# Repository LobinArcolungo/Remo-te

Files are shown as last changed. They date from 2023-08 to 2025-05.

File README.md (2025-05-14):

# Remo-te

## Remo-te?
YES! This project aims to build an automated machine for tea brewing!<br>
Imagine jumping into your car after work and having to drive for quite some time. Wouldn't be great if once you get home a hot cup of freshly brewed tea is waiting for you just at the perfect temperature for you to not burn your tongue? And what if this was just a tap away from your finger?
<br>
<br>
Now that's what we are talking about! and you ca find beelow all the documentation that i wrote during the process of making this machine. Take it not as a tutorial but more as an inspiration for your very own version.<br>
<br>

## Materials
### for the electronic part we will need
- Arduino nano for hardware driving.
- ESP 8266 or Arduino nano IoT for cloud connection.
- 2 Relays 5Vdc 10A.
- 2 Micro Servo 9g MS18.
- L298N driver for stepper motor.
- Power supply 12v 3A.
- Power supply 5V 1A for autonomus powering the boards, the relais and the servo motors.
- A generic 12V pump and a small pipe.
- A stepper motor, i used 17OM-J349-G2VS Minabea Motor.
- A Breadboard to hold all the components.
- A triple plug to join al the power cables into one plug to be attached to the house power grid.

### for the mechanical part we will need
- To print all the .stl files in the "prints" folder
- A water tank to hold the water
- An electrical boiler with auto-shut-off function when boiling point is reached
- A plastic pulley
- A box to hold the circuitry
- About 3 meters of thin fishing line: a piece is used to connect the servo motor which will turn on the boiler and another piece has to be divided in three pieces and braided to make it stronger which will hold the boiler during the pouring process.
- (optional) A bearing to make the twine flow easily
- Of course a teapot to pour te water in!

## Circuit
In the folder "circuit" can be seen the history of the circuits. The last version is this one
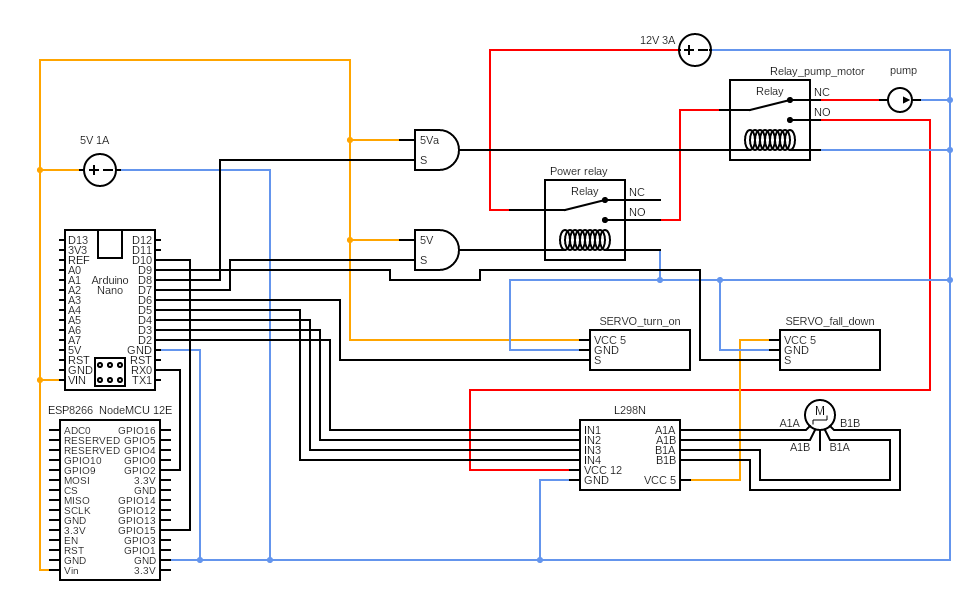
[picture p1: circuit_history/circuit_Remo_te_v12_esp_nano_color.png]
Alt Image of the circuit


The boards are powered autonomously with the 5V 1A power supply.
The pins involved for the Arduino nano are:
- 2,3,4,5 respectively for the first coil (2,3) and the second coil (4,5) of the stepper motor
- 6 controls the servo motor which turns the boiler power on
- 7 controls the power supply relay
- 8 controls the "power router" relay which choses between pump and stepper motor 
- 9 controls the servo motor which starts the falling process
- 10 sends to the ESP board a signal "TE_READY" when the preparation is ended
- RX for serial UART receiver

The pins involved for the ESP are:
- D4 (or GPIO 2) for UART transmission
- D8 (or GPIO 15) for TE_READY signal

this is a photo of my setup.
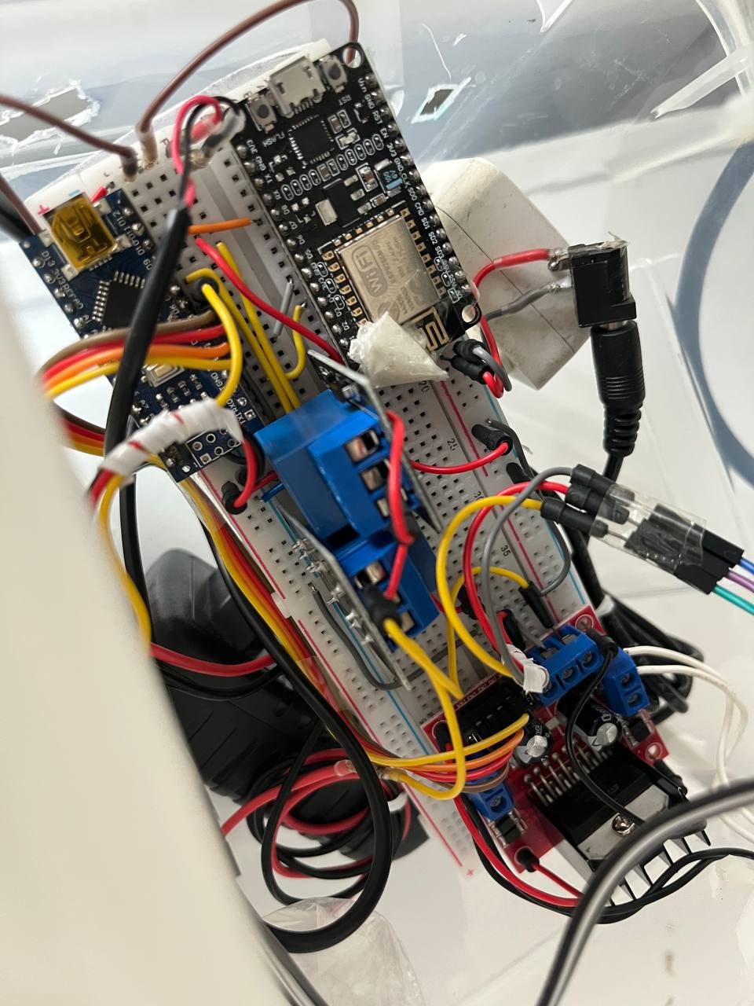
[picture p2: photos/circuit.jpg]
Alt Photo of the circuit


and a circuit made with fritzing
![Alt Image made with fritzing]()

## Code
The most updated code is the folder, one with 
It provides a series of functions callable from serial communication and allows to test all the functionalities one by one. The code is commented and i think it is pretty easy to understand

## Mechanical building
The assembling process is simple and easily customizable depending on your setting. the only few important rules are 
- the water tank should lay below the boiler otherwise the pump will let the water flow into the boiler
- the circuit board should rest in a place relatively safe from water drops
- the motor should stay in the specific housing in the printed part "remo_te dock.stl"
- the pulley should be attached to the motor and should roll and unroll the fishing line to make the boiler pour the hot water

## Video
Here can be found the demostrating video of the functioning

Video showing remote tea making functionality

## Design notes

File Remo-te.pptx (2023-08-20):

## Remo-te

Making... some tea

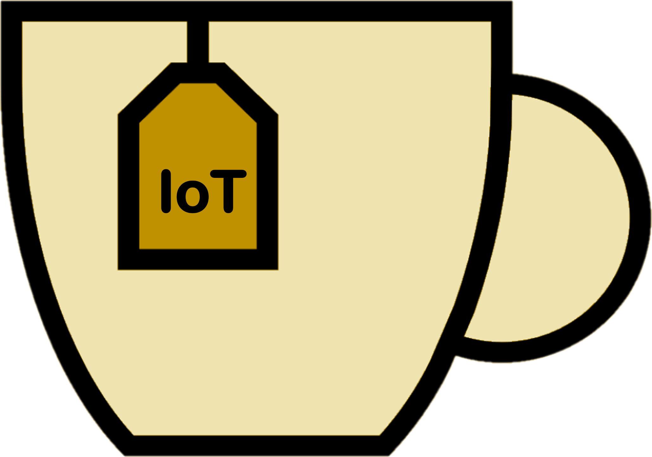
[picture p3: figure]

Giacomo Cerino - Agosto 2023

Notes: Buongiorno a tutti oggi vi parlerò del mio progetto, remo-te, dove te sta per tè, quello che si beve.

## Remo-te

Making... some tea

L’idea

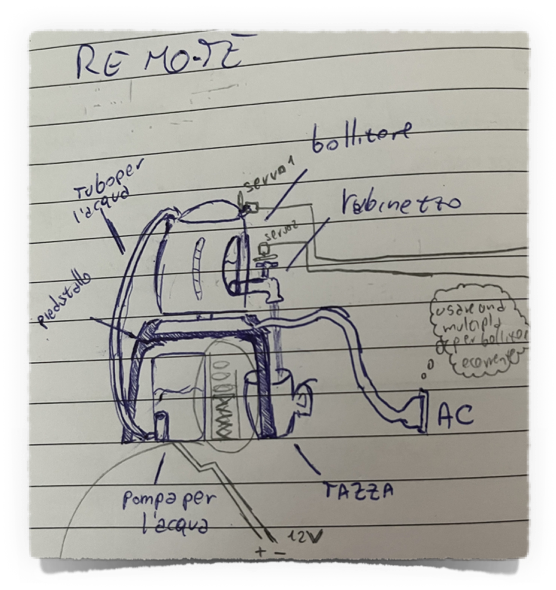
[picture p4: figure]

Giacomo Cerino - Agosto 2023

Remo-te

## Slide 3

L’idea

Preparare il tè
Automaticamente
Con un tap su un’applicazione

Remo-te

Giacomo Cerino - Agosto 2023

I problemi

Motore

Caduta

Comunicazione

Voltaggio

Stampa 3D

Attrito

Elettrovalvola

Bustina di te

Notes: L’idea è quella di avere un dispositivo capace di preparare il te in maniera automatica e non supervisionata.
Attraverso un controllo remoto semplice si può così preparare una tazza di te con largo anticipo e averlo perciò a temperatura ambiente, pronto per essere raffreddato con un po’ di ghiaccio oppure fare in modo che all’arrivo il te sia ben caldo per le giornate invernali. Qui possiamo vedere il bozzetto iniziale in cui era previsto l’utilizzo di una pompa per riempire il bollitore, un rubinetto per versare l’acqua calda nella tazza, e un abbozzato sistema di caricamento delle bustine di tè. Per accendere il bollitore e controllare il flusso d’acqua avrei usato dei servomotori e il tutto sarebbe stato montato su un piedistallo stampato in 3D. Tutto semplice no?

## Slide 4

L’idea

Giacomo Cerino - Agosto 2023

I problemi

Motore

Caduta

Comunicazione

Voltaggio

Stampa 3D

Attrito

Elettrovalvola

Bustina di te

Remo-te

Giacomo Cerino - Agosto 2023

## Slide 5

Motore

Stampa 3D

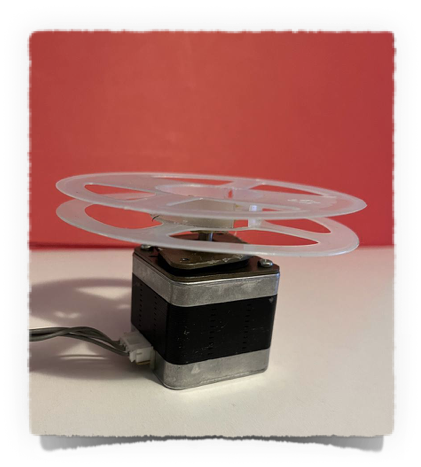
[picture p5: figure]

Elettrovalvola

I problemi

Attrito

Bustina di te

Caduta

Comunicazione

Giacomo Cerino - Agosto 2023

Voltaggio

Remo-te

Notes: Ecco…
Questi sono i problemi che mi sono trovato ad affrontare non li affronterò tutti nel dettaglio perciò spenderò due parole adesso su ognuno.
Il primo è l’elettrovalvola. Il mio progetto di estrarre l’acqua calda molto semplicemente grazie alla gravità è stato bocciato in quanto giudicato fallimentare dal commesso del negozio di idraulica in cui mi sono recato ().
Perciò il design del progetto è radicalmente cambiato e ha fatto scaturire tutta una serie di altri problemi.
Il motore, e l’attrito su cui arriveremo dopo. Il problema della stampa 3D è un problema di tempistiche, in quanto avevo solo una possibilità di stampare i pezzi voluminosi prima della pausa estiva degli uffici di alma labor.
Il problema della caduta è attualmente risolto in parte in quanto non è garantito che il meccanismo funzioni sempre. Comunque è stato risolto da un servomotore, il problema della bustina di te è considerabile risolto ma con una versione beta in quanto c’è un problema di sgocciolamento e ampio margine di miglioramento del meccanismo.

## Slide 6

Stampa 3D

Motore

I problemi

Funzionamento dei motori passo passo
Driver dedicato
Scrittura del software
Gestione surriscaldamento

Attrito

Elettrovalvola

Bustina di te

Caduta

Remo-te

Giacomo Cerino - Agosto 2023

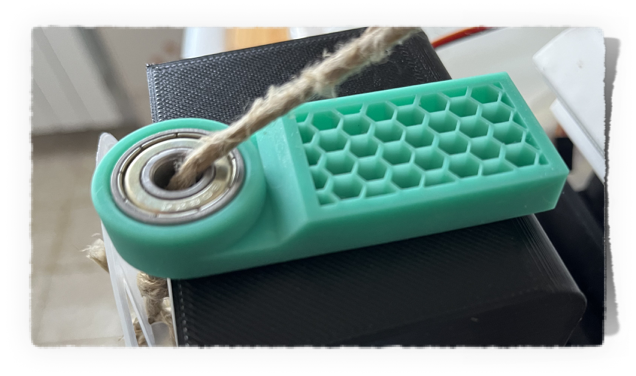
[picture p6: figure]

Attrito

Voltaggio

Comunicazione

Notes: Il motore passo passo che avevo a disposizione non poteva essere controllato da arduino da solo e neanche da un normale chip per motori, cioè un ponte H. serviva un chip dedicato di cui fortunatametne disponevo e con cui mi sono dovuto interfacciare e capire le meccaniche. Non ho usato librerie già pronte ma piuttosto ho seguito una guida di un canale youtube (ScienceFun) il cui codice permette anche di determinare la potenza con cui muovere il motore… ciò più avanti avrebbe generato un problema… infatti fino alla risoluzione del problema della caduta, ho lavorato sempre su una scheda arduino nano, in vista poi di traslare il codice su un ESP 8266

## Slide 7

Motore

Attrito

Voltaggio

I problemi

Strofinamento
Disegno 3D
Minimizzazione del volume

Remo-te

Giacomo Cerino - Agosto 2023

Vs

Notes: L’attrito è stato un problema diciamo, non fondamentale da risolvere a prima vista, ma in realtà l’attrito oltre a rovinare il tirante ch eè, si, facilmente sostituibile (perché fino a quel punto era fatto di spago) richiede anche molta più energia da parte del motore in quanto parte della potenza viene dissipata durante lo strofinamento.

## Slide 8

Attrito

Voltaggio

I problemi

Transistor e Relays
Componenti incompatibili
Usare meno schede possibili

Comunicazione

UART

Vs

Remo-te

Giacomo Cerino - Agosto 2023

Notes: Come dicevo prima

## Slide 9

Le tecnologie:

Voltaggio

I problemi

Differenza del numero di porte seriali
Impossibilità di debug e funzionamento simultaneo
Compromesso

Comunicazione

UART

Vs

Remo-te

Giacomo Cerino - Agosto 2023

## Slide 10

Voltaggio

I problemi

Differenza del numero di porte seriali
Impossibilità di debug e funzionamento simultaneo
Compromesso

Comunicazione

Le tecnologie:

UART

Vs

Remo-te

Giacomo Cerino - Agosto 2023

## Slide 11

Voltaggio

I problemi

Differenza del numero di porte seriali
Impossibilità di debug e funzionamento simultaneo
Compromesso

Comunicazione

Le tecnologie:

Comunicazione bidirezionale asincrona

UART

Vs

Remo-te

Giacomo Cerino - Agosto 2023

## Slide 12

Le tecnologie:

51%

UART

Segnale digitale di notifica +
Comunicazione monodirezionale asincrona

Remo-te

Remo-te

Giacomo Cerino - Agosto 2023

Arduino e ESP8266

Transistor e Relays

Stepper
Motor

Design e stampa 3D

Servo motori

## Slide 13

Il circuito

51%

Le tecnologie:

Arduino e ESP8266

UART

Transistor e Relays

Stepper
Motor

Design e stampa 3D

Giacomo Cerino - Agosto 2023

Servo motori

Remo-te

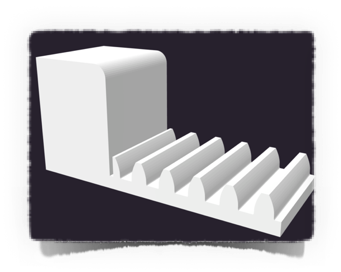
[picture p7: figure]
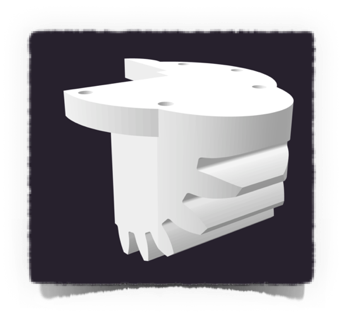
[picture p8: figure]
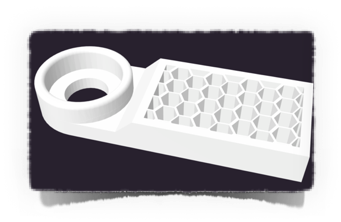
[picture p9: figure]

Segnale digitale di notifica +
Comunicazione monodirezionale asincrona

Remo-te

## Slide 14

Transistor e Relays

UART

Le tecnologie:

Arduino e ESP8266

Design e stampa 3D

Stepper
Motor

Servo motori

Remo-te

Giacomo Cerino - Agosto 2023

Segnale digitale di notifica +
Comunicazione monodirezionale asincrona

Remo-te

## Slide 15

Il circuito

51%

Le tecnologie:

Arduino e ESP8266

UART

Transistor e Relays

Stepper
Motor

Design e stampa 3D

Giacomo Cerino - Agosto 2023

Servo motori

Remo-te

Segnale digitale di notifica +
Comunicazione monodirezionale asincrona

Remo-te

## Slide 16

IoT Cloud

Variables
Devices
Dashboard
Things
Web Editor

Le tecnologie:

Il circuito

Remo-te

Giacomo Cerino - Agosto 2023

Arduino e ESP8266

IoT Remote

UART

Microcontroller

Transistor e Relays

Stepper
Motor

Design e stampa 3D

Servo motori

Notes: Due power supply,
i relays sono un po’ modificati,
il bollitore non è nel circuito

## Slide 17

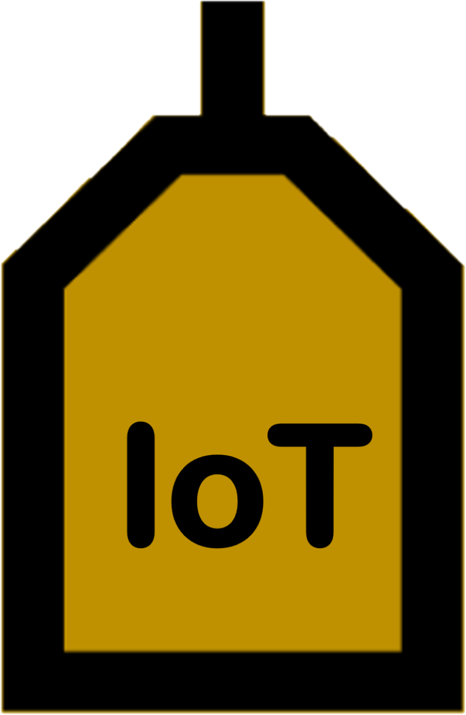
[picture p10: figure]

Il Remo tè

IoT Cloud

Variables
Devices
Dashboard
Things
Web Editor

Il cloud

Microcontroller

IoT Remote

Remo-te

Giacomo Cerino - Agosto 2023

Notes: Cos’è IoT Cloud
IoT Remote
Codice
Come mi interfaccio al cloud

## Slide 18

Il Remo tè

IoT Cloud

Variables
Devices
Dashboard
Things
Web Editor

Il cloud

Microcontroller

IoT Remote

Remo-te

Giacomo Cerino - Agosto 2023

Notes: Cos’è IoT Cloud
IoT Remote
Codice
Come mi interfaccio al cloud

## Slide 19

Il cloud

Il Remo tè

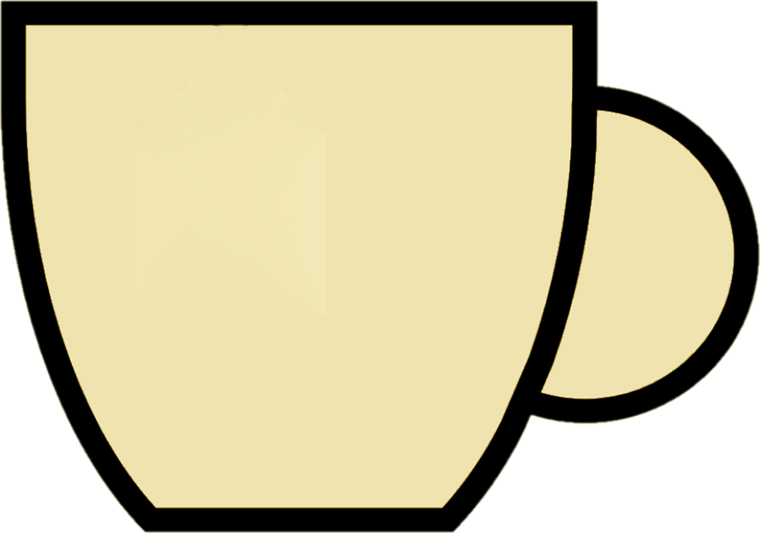
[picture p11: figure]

Dovrebbe essere pronto

Giacomo Cerino - Agosto 2023

Remo-te

IoT Cloud

Variables
Devices
Dashboard
Things
Web Editor

Microcontroller

IoT Remote

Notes: Di nuovo bustina di te

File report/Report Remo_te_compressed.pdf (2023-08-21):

# Remo-te

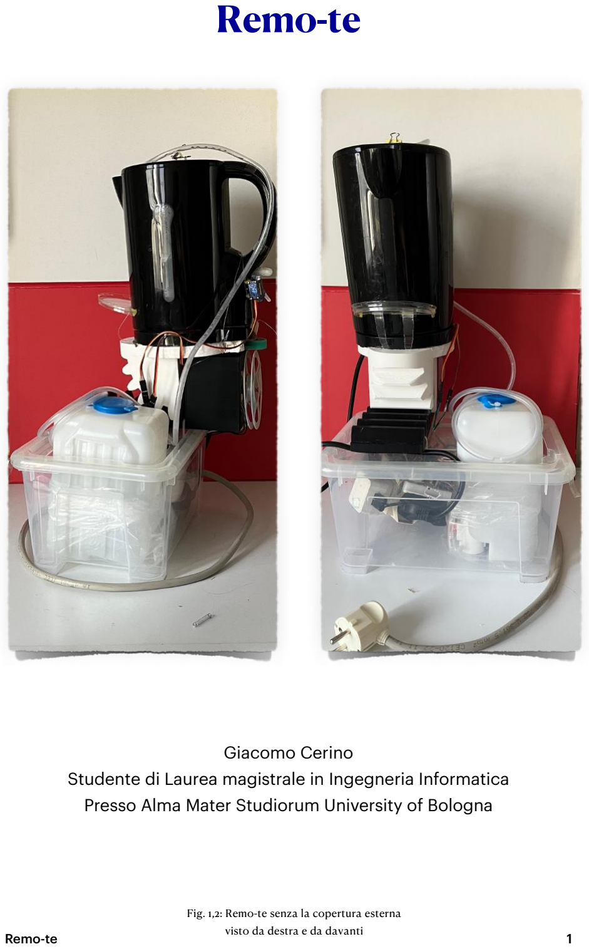
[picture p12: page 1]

Giacomo Cerino
Studente di Laurea magistrale in Ingegneria Informatica Presso Alma Mater Studiorum University of Bologna
Remo-te | 1

Fig. 1,2: Remo-te senza la copertura esterna visto da destra e da davanti

## Indice

Indice | 2
Introduzione | 3
Il progetto iniziale | 4
Sviluppo della soluzione | 4
Problema dell’elettrovalvola | 5
Problema della stampa 3D | 5
Problema del motore | 6
Problema dell’attrito | 8
Problema della caduta | 10
Problema del voltaggio | 11
Problema della comunicazione tra schede | 12
Problema della bustina di te | 13
Interfacciamanto a ArduinoCloud | 14
Materiali e metodi utilizzati | 14
Modellazione 3D | 14
Stampa 3D | 14
Schede utilizzate | 15
Componenti elettronici | 15
Componenti non elettronici | 16
Disegno del circuito | 16
Programmazione delle schede e debug | 16
Interfacciamento al Cloud | 17
Risultati ottenuti | 17
Sviluppi futuri | 17
Telegram bot | 18
Aggiunta parametri come zucchero e tempo di infusione | 18
Aggiunta di sensori | 18
Open Source | 18
Bibliografia e Sitografia | 19
Remo-te | 2

## Introduzione

Il progetto è nato come una sfida per raggiungere un certo livello di comodità nella preparazione del te. A molte persone il te piace caldo e appena preparato, a me per esempio piace freddo. Il problema con il te freddo è che bisogna prima prepararlo per infusione in acqua calda e poi aspettare che si raffreddi.
Per velocizzare questo processo si potrebbe utilizzare un frigorifero o del ghiaccio. Entrambe queste due soluzioni generano problemi: mettendo il te nel frigorifero si alza di molto la temperatura del frigorifero in quanto in un ambiente a circa 4°C si introduce un elemento a più di 90 °C. Inoltre viene generata della condensa che per la mia esperienza peggiora il sapore del te rendendolo più amaro. Utilizzando del ghiaccio il tè inevitabilmente si diluisce e inoltre bisogna accertarsi di disporre del ghiaccio nel freezer.
Perciò mi è venuto in mente che sarebbe comodo poter avviare con un certo anticipo rispetto al mio arrivo a casa la preparazione di una certa quantità di te. Il risultato del processo autonomo di infusione mi aspetterà a casa raffreddandosi. Chiaramente questo progetto è adatto anche a preparare il te mentre si è sulla via del ritorno dal lavoro. In modo che arrivati a casa il te sia ancora caldo.
Remo-te | 3

## Il progetto iniziale

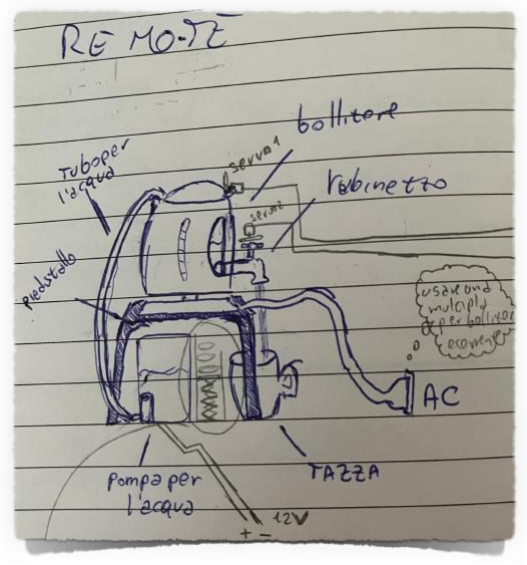
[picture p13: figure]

Il progetto iniziale doveva essere un macchinario abbastanza semplice che utilizzava una pompa per riempire un bollitore, un servomotore per innescare il processo di bollitura e una ulteriore pompa per pompare l’acqua calda nella tazza o nella teiera. Inoltre era previsto u n s i s t e m a d i a r r o t o l a m e n t o e srotolamento della cordicella di una bustina di te in modo da poter controllare anche il tempo di infusione. Alla base del bollitore era prevista l'aggiunta di un “rubinetto controllato e l e t t r o n i c a m e n t e ”, c o m e u n
elettrovalvola o un dispositivo da
giardinaggio.
Il bozzetto del design era abbastanza compatto prevedeva di assomigliare a una macchinetta del caffè dalla cui parte bassa si poteva estrarre la tazza piena di te.

## Sviluppo della soluzione

In questa sezione descrivo la successione dei problemi che si sono presentati durante la realizzazione. In pratica è un riassunto di tutti i passaggi e le iterazioni che hanno portato al primo prototipo funzionante.
Ho cominciato comprando online una pompa provvista di serbatoio per acqua. La scelta è ricaduta su una pompa universale per tergicristalli. Essendo pronta all’uso avrei solo dovuto provvedere all'energia elettrica. Prima di utilizzarla per preparare del te ho trattato il serbatoio con dell'aceto e del bicarbonato per rimuovere il cattivo odore che sprigionava.
Nel frattempo ho comprato un bollitore in un negozio dell’usato e mi sono recato in un negozio di componenti elettronici e idraulici dove ho comprato due
Remo-te | 4

Fig. 3: Bozzetto iniziale relais e ho chiesto informazioni riguardo all'idea dell’elettrovalvola e mi hanno consigliato un posto più specializzato dove recarmi.

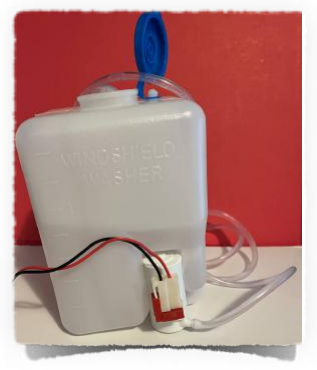
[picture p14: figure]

### Problema dell’elettrovalvola

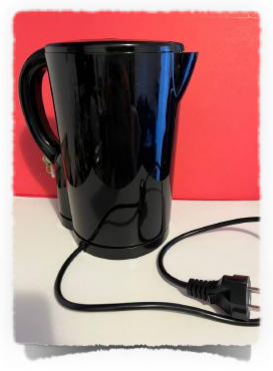
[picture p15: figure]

Una volta recatomi in loco, il commesso mi ha risposto che l'idea originaria di perforare il bollitore per aggiungere l’elettrovalvola oltre che abbastanza costosa sarebbe stata fallimentare in quanto sicuramente la tenuta stagna si sarebbe presto guastata a causa della dilatazione termica dovuta la variazione della temperatura dell'acqua che per definizione si genera dentro un bollitore.
Soluzione: Tornato a casa mi sono messo a pensare a una soluzione alternativa per ottenere comunque il risultato previsto dal progetto. E ho pensato a un sistema di ingranaggi in grado di inclinare il bollitore in modo da versare gradualmente l'acqua dentro un recipiente e poi ripristinare la sua posizione verticale.

### Problema della stampa 3D

Ho disegnato il sistema di ingranaggi in 3D aiutandomi con un CAD e mi sono recato in un laboratorio dell'università per farmeli stampare con stampanti FDM in PLA. Purtroppo viste le imminenti vacanze estive ho potuto fare solamente una stampa e come è facile intuire il mio disegno aveva delle imperfezioni di cui mi sono reso conto solamente una volta ottenuti i pezzi.

Fig. 4: Pompa universale per tergicristalli con tubo e
serbatoio

Fig. 5: Bollitore elettrico da 1.7l di capacità massima

Remo-te | 5

La progettazione e la stampa di pezzi in 3D è anche detta prototipazione veloce. Per avere un prototipo funzionante di solito ci vuole qualche iterazione in modo da perfezionare il design ma in questo caso non è stato possibile.
Soluzione: Seppur imperfetti, i pezzi che avevo ottenuto riuscivano a soddisfare il bisogno primario per cui li avevo stampati, ovvero incastrarsi fra loro e ruotare di 90° l’uno sull’altro. L'imperfezione era l’incastro con la parte inferiore del bollitore, ma lavorando una mattina con un saldatore, un Dremel, e un adattatore fatto in cartone sono riuscito a produrre un incastro che funziona. Ad ogni modo non avrei avuto la possibilità di stampare a filamento altri pezzi così voluminosi fino a settembre.

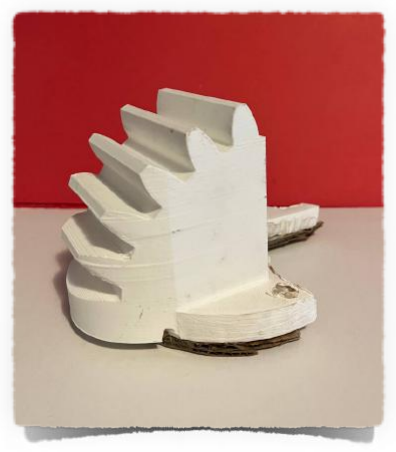
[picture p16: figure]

### Problema del motore

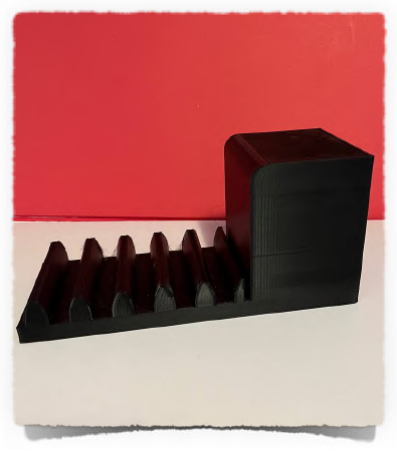
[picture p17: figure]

Per azionare il sistema di ingranaggi in modo automatico sarebbe stato necessario l'utilizzo di un motore a cui avrei attaccato una puleggia per allungare o diminuire la lunghezza di un tirante che mantiene in equilibrio il bollitore. A casa avevo a disposizione un motore passo passo di cui non ricordo la provenienza. La sfida è diventata quella di farlo funzionare in modo soddisfacente.

Remo-te | 6

Fig. 6: Boiler, ovvero il pezzo da attaccare al bollitore

Fig. 7: Dock, ovvero il pezzo su cui si appoggerà il bollitore

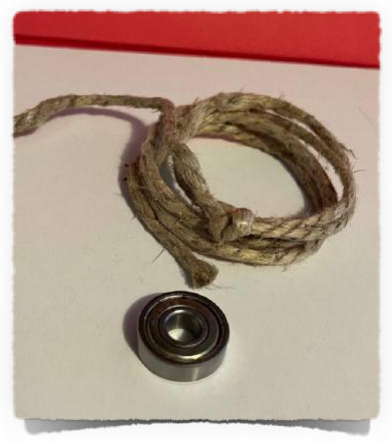
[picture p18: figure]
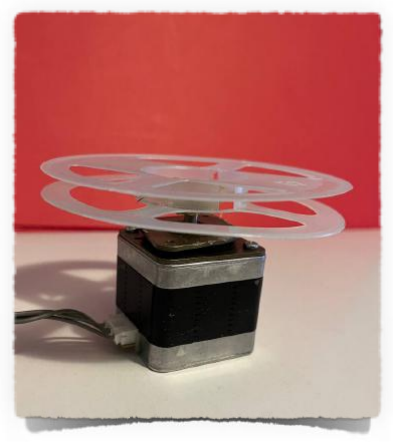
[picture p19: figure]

In quel momento io avevo a disposizione solamente un Arduino UNO e perciò cominciai a sperimentare utilizzando soltanto i segnali dell’Arduino UNO. Dopo poco tempo mi sono reso conto che avrei avuto bisogno di un driver per motori passo passo. Avendo come ostacolo sempre le vacanze
estive ho cercato di trovare una soluzione che non
prevedesse l'acquisto di uno di questi driver.
Operando una ricerca tra i componenti elettronici che avevo a disposizione ho trovato un driver L9110 adatto per la guida di due motori a corrente continua oppure un motore passo passo. Ho cominciato a scrivere il codice utilizzando questo driver ma dopo qualche esperimento mi sono reso conto che il problema era che il mio motore passo passo
richiedeva una quantità di corrente e tensione tale che
non poteva essere gestita da questo chip.

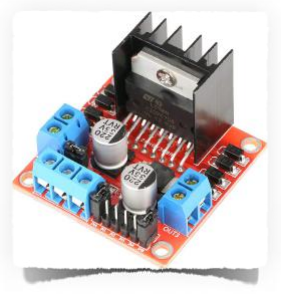
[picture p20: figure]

Soluzione: Mi sono ricordato a questo punto che un mio amico mi aveva portato un driver L298N. Un driver vecchio per due motori a corrente continua o un motore passo passo. Un motore che ha dei noti problemi in quanto si surriscalda fin troppo facilmente spegnendosi ma tutto sommato un motore che poteva gestire

Remo-te | 7

Fig. 9: Cuscinetto a sfera e spago che inizialmente era usato come tirante.

Fig. 8: Motore passo passo “17OM-J349-G2VS Minabea Motor” con puleggia di plastica incollata

Fig. 10: Driver L298N

(fino a un certo punto) la corrente che gli avrei fornito. Mi sono messo perciò a scrivere il codice su Arduino per provare a guidare il motore attraverso il driver e per ottenere una versione funzionante mi è stato molto utile guardare alcuni video su YouTube [2],[3], e in particolare il video di Science Fun [1].
Come ho detto il driver del motore è soggetto a surriscaldamento e spegnimento improvviso, perciò è fondamentale fornire energia al motore soltanto per il tempo strettamente necessario. Per fare ciò ho usato i due relais per creare un sistema di gestione della corrente in grado di spegnersi appena il motore non sia più necessario.

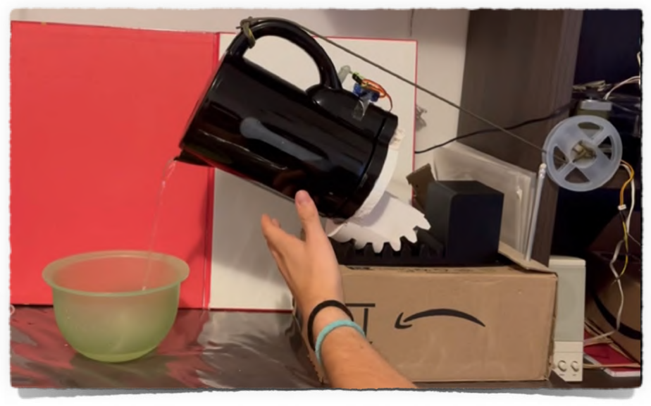
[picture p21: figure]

### Problema dell’attrito

Inizialmente il tirante che avevo pensato di usare era fatto di spago (ancora prima da un laccio di una scarpa). Uno dei difetti del design dei pezzi stampati in 3D era che avevano alcuni spigoli non smussati. Perciò lo spago scorrendo e sfregando

Remo-te | 8

Fig. 11: Fotogramma di uno dei primi video in cui stavo provando per la prima volta il sistema del motore con la puleggia. Si può vedere come i due pezzi stampati in 3D si incastrano tra loro, il bollitore possa essere acceso con un servo motore applicato sul retro, la puleggia srotoli e arrotoli un laccio da scarpe che avevo usato come tirante, l’acqua fuoriesca dal bollitore per finire in un recipiente.

sullo spigolo si sarebbe presto deteriorato, questo mi ha fatto pensare al problema dell’attrito.
L'attrito rovina il tirante e stressa di più il motore richiedendo più dispendio di energia.
Soluzione: Ho disegnato in 3D un alloggio per un cuscinetto a sfera attraverso il quale far passare il tirante basandomi su un design di Hondjog1 (https://www.thingiverse.com/Hondjog1) [4],[5]. Non è il metodo più efficiente per eliminare l'attrito ma il metallo genera molto meno attrito e la componente mobile del cuscinetto agevola eventuali rotazioni del tirante. Ho detto prima che non avrei avuto la possibilità di stampare questo pezzo con una stampante a filamento, e infatti in questa occasione ho usato la mia stampante a resina. Stampare prototipi in resina non è particolarmente indicato perché:
- È sconsigliabile stampare grandi volumi: la resina non può avere spazi vuoti all'interno dei modelli in quanto essendo liquida rimarrebbe all'interno e non verrebbe solidificata con il processo di curing.
- Nel caso in cui si stampino pezzi che devono combaciare al millimetro con altri, è consigliabile utilizzare un orientamento verticale dell'asse di incastro in modo tale da non avere problemi di deformazione durante la stampa.
Remo-te | 9

(Sopra) Fig. 12: Foto dell’alloggio per cuscinetto a sfera, come si può vedere è stampato in resina e ha molti fori esagonali per diminuire molto il volume della resina utilizzata ma mantenere la stabilità e la rigidezza, inoltre i fori sono stati molto utili per incollarlo al pezzo sottostante. (Notare lo spigolo nero).
(Sinistra) Fig. 13: Fotogramma del primo video in cui ho preparato un vero e proprio te. È ripreso dall’alto. La scatola è ancora di cartone e l'alloggio per il cuscinetto a sfera è ancora fatto con materiali di fortuna per evitare l'eccessivo sfregamento

Per questo motivo il disegno che ho fatto occupa poco volume effettivo perché ha numerosi fori esagonali. Inoltre l'alloggio per il cuscinetto a sfera è stato stampato con l'asse di incastro allineata con quella verticale e perciò è stato un successo alla prima stampa.
In aggiunta ho sostituito il tirante di spago con un tirante fatto di lenza da pesca intrecciata in modo da aumentare la resistenza e avere uno stile più elegante.

### Problema della caduta

A questo punto avevo ottenuto un sistema funzionante di gestione dell'inclinazione del bollitore. L’unico guaio era che il bollitore in posizione di equilibrio non era soggetto all'influenza del motore, in pratica doveva essere sbilanciato in modo da poter poi essere inclinato a piacere grazie al motore. Soluzione: grazie a un servo motore collocato sotto la base del bollitore si riesce a sbilanciare quest'ultimo in avanti grazie a una rotazione del braccio di 90°.

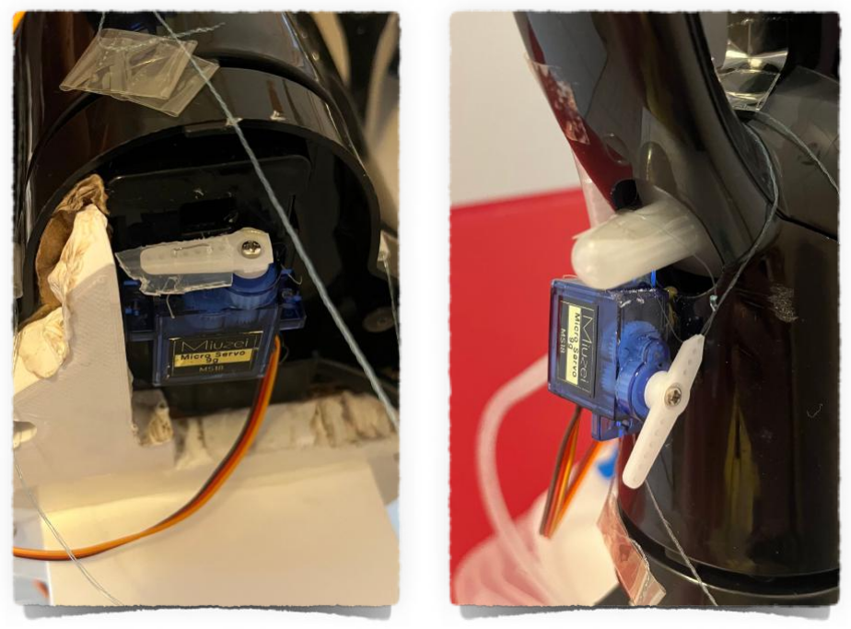
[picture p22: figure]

Remo-te | 10

Fig. 14: Servo motore applicato
alla base del bollitore

Fig. 15: Servo motore che si occupa dell’accensione del bollitore ruotando in senso orario

Ne approfitto visto che stiamo parlando di servomotori per spiegare che il sistema di accensione del bollitore è anch’esso operato da un servo motore che tira una cordicella di lenza da pesca corta in modo da azionare l'interruttore che poi ritornerà alla posizione iniziale quando il bollitore si spegnerà da solo.
Problemi noti: Il servo motore non è particolarmente performante e perciò non riesce a sollevare il peso del bollitore se esso è completamente aderente alla superficie del Dock e contiene più di un litro d’acqua. Per questo il motore viene sempre tenuto leggermente inclinato in modo che il servo motore possa eseguire con successo la sua funzione.

### Problema del voltaggio

Dopo aver ottenuto una versione funzionante del primo prototipo che utilizzava Arduino come micro controllore, mi sono messo a traslare il codice sulla scheda ESP8266 Node MCU 12.1. La quale essendo provvista di un modulo Wi-Fi ha la capacità di connettersi a Arduino cloud.
Sebbene inizialmente mi era sembrato un compito facile in quanto le due schede condividono il supporto per il linguaggio di programmazione di Arduino, mi sono presto accorto che il voltaggio operativo delle due schede era differente. Mmentre Arduino opera a 5V ed è quindi in grado di fornire segnali digitali e analogici fino a 5V, la scheda ESP8266 invece opera a 3.3V ed è perciò in grado di inviare segnali digitali e analogici soltanto fino a 3.3V. Per i segnali digitali non sussiste nessun problema in quanto 3.3V è interpretato come logic high anche da componenti che lavorano 5V. Invece per i segnali annalogici la questione è differente: il codice scritto per guidare il motore passo passo utilizza segnali analogici nel range [0,5V]. Dove a 5V si raggiunge la coppia massima per il motore. Questo è importante perché durante il processo di raddrizzamento del bollitore serve più energia di quanta ne serva per farlo inclinare.
Dopo vari esperimenti ho constatato che 3.3V non erano abbastanza per comunicare al motore la potenza necessaria per il raddrizzamento. O almeno non con il Driver L298N.
Insieme alla scheda ESP8266 avevo ordinato anche la sua maschera (ESP8266 motor shield) capace di aumentare i pin disponibili e provvedere, grazie a un'alimentazione esterna, alla gestione di un motore passo passo. Nonostante io ci abbia speso un
Remo-te | 11

paio di giorni sopra, ho trovato poca documentazione a riguardo e quella che ho trovato non mi ha permesso di ottenere un funzionamento del motore accettabile. Soluzione: Dopo aver passato giorni a cercare di tradurre i segnali analogici [6] nel range [0,3.3V] al range [0,5V] ho deciso che la soluzione più pratica sarebbe stata quella di utilizzare due schede. ESP8266 per interfacciarsi al cloud e Arduino nano per controllare tutti i componenti hardware che funzionano a 5V.

### Problema della comunicazione tra schede

Una volta deciso che avrei usato due schede si è posto il problema di come sarebbe avvenuta la comunicazione tra le due.
Ho pensato di usare dei segnali digitali basilari per inviare comandi molto semplici ma avendo studiato durante il corso i protocolli di bus e in particolare il protocollo UART ho deciso di provare con quello. Ho presto scoperto però che mentre ESP8266 ha due porte seriali UART, Arduino nano ne ha solo una.
Ho fatto svariate prove per trovare una soluzione che ponesse il sistema in grado di comunicare in entrambe le direzioni con il protocollo UART.

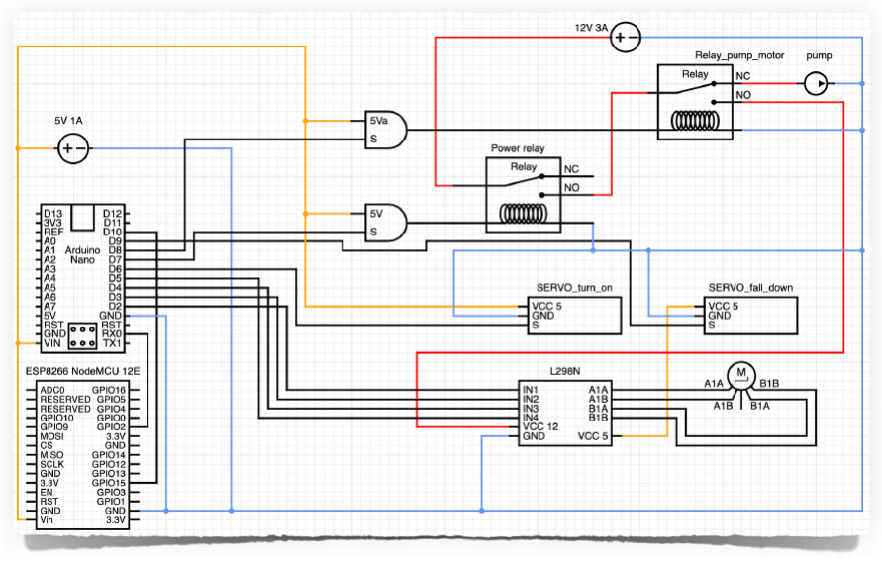
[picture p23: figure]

Remo-te | 12

Fig. 16: Circuito che illustra come le schede sono collegate ai componenti e fra loro

Soluzione: Dopo questi esperimenti ho capito che la cosa migliore data la mia necessità era quella di utilizzare la comunicazione UART soltanto nella direzione da ESP a Arduino nano. E visto che Arduino nano aveva tra i suoi compiti di comunicazione soltanto quello di notificare il momento in cui il te sarebbe stato pronto, nella direzione da Arduino nano a ESP ho utilizzato soltanto un segnale digitale.

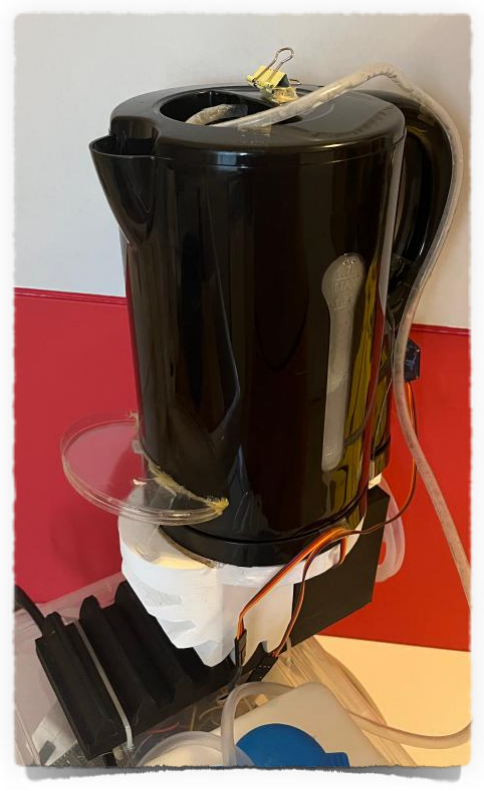
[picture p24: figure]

### Problema della bustina di te

Per come era stato formulato inizialmente il progetto sarebbe stato necessario fornire la possibilità di alzare e abbassare la bustina di te in modo da garantire un determinato tempo di infusione. Tuttavia avendo riscontrato problemi con l'elettrovalvola inizialmente, ho dovuto concentrarmi sulla soluzione di quel problema. Una volta risolto quel problema ho pensato che avrei potuto "riciclare" il movimento del bollitore per muovere anche la bustina di te
Soluzione (anche se classificabile come una beta): Creare la possibilità di fissare al bollitore una bustina di te grazie a un magnete. E aspettare il tempo di infusione prima di risollevare il bollitore in posizione verticale. Inoltre ho aggiunto un piccolo piatto per raccogliere le gocce di te che cadranno dalla bustina.
Remo-te | 13

Fig. 17: Una delle ultime iterazioni, si può notare un piattino di plastica che serve a raccogliere le gocce e una molletta nella parte superiore a contatto con un magnete per fissare la bustina di te

### Interfacciamanto a ArduinoCloud

Durante la risoluzione dei problemi di cui sopra, ho anche portato avanti degli esperimenti per far funzionare l’interfacciamento e la connessione con Arduino Cloud. Ciò che ho constatato è che l’ESP8266 non è sempre collaborativo in quanto a volte rifiuta di connettersi alla rete, e a volte anche se si connette alla rete non si connette con il cloud senza fornire informazioni riguardo agli errori riscontrati. Nella mia esperienza la frequenza di questi avvenimenti è randomica e imprevedibile. La soluzione più comoda sarebbe quella di usare un Arduino nano 33 IoT, provvisto della funzionalità wi-fi e perfettamente integrato con Arduino Cloud.

## Materiali e metodi utilizzati

### Modellazione 3D

La modellazione 3D di questo progetto è stata fatta interamente con Autodesk Fusion 360 in quanto è un software che negli anni ho imparato autonomamente a utilizzare perciò mi sono trovato in un ambiente familiare, in cui sapevo come muovermi.

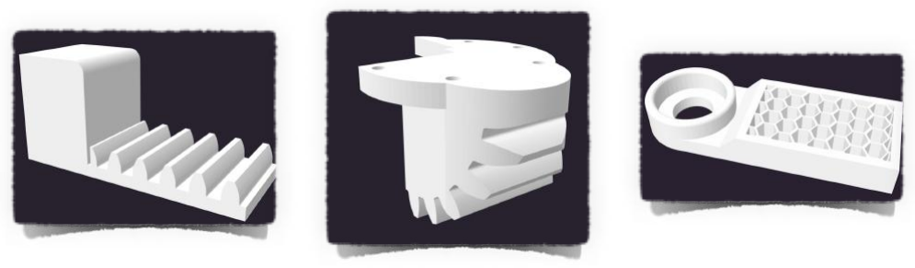
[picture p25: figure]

### Stampa 3D

I primi due pezzi che ho stampato (Dock e Boiler) sono stati stampati con una stampante a filamento in materiale PLA, senza avere particolari caratteristiche di durezza, morbidezza o elasticità. Il terzo pezzo ovvero l'alloggio per cuscinetto a sfera (Bearing_housing) invece è stato stampato con una stampante a resina Elegoo

Remo-te | 14

Fig. 17,18,19: Imagini dei file .stl dei tre pezzi stampati

Saturn in resina lavabile in acqua di colore verde chiaro e applicato successivamente al pezzo chiamato Dock con della colla a caldo.

### Schede utilizzate

Per questo progetto sono effettivamente necessarie solamente due schede:
- ESP8266 node MCU 12.1 (o scheda analoga capace di connettersi a Arduino Cloud).
- Arduino nano (o scheda analoga capace di fornire segnali a 5V).
Tuttavia per fare vari esperimenti anche con i servomotori io mi sono servito di un ulteriore Arduino UNO che potevo maneggiare con più facilità in quanto non era già inserito nel circuito del dispositivo completo.

### Componenti elettronici

- 2 Relays 5V dc 10A.
- 2 Micro Servo 9g MS18.
- L298N driver per motore passo passo.
- Power supply 12v 3A.
- Power supply 5V 1A per fornire energia alle schede .
- Una generica pompa a 12V e un piccolo tubo.
- Un motore passo passo, io ho usato un “17OM-J349-G2VS Minabea Motor”.
- Una Breadboard per sorreggere tutti i componenti.
- Una presa multipla per unire tutti i dispositivi connessi alla corrente.

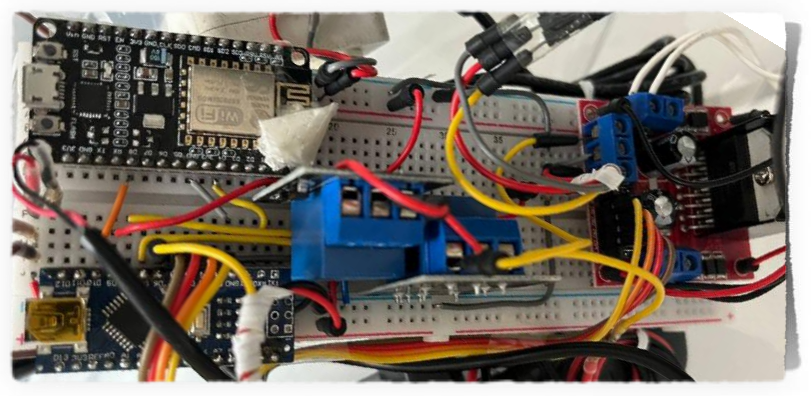
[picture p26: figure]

Remo-te | 15

Fig. 20: Immagine del circuito visto dall’alto

### Componenti non elettronici

- Un cuscinetto a sfera.
- Una scatola per contenere il tutto.
- Della lenza da pesca.
- Una piccola puleggia.
- Nastro adesivo.
- Un piccolo raccoglitore per l’acqua che sgocciola dalla bustina di te.
- Una molletta.
- Un magnete.
- Fascette da elettricista per fissare il Dock alla scatola.

### Disegno del circuito

Per disegnare il circuito mi sono servito di un sito facile e intuitivo da usare che si chiama circuit diagram [7]. Qui ho trovato la maggior parte dei componenti già pronti, anche se alcuni come la scheda ESP li ho dovuti creare personalmente. Tutto sommato non è stato difficile, però dispendioso in termini di tempo.

### Programmazione delle schede e debug

Per la programmazione dei microcontrollori ho utilizzato in minima parte Arduino IDE per poi passare a Visual Studio Code integrato con l'estensione per Arduino. Visual studio code ha moltissime scorciatoie da tastiera per modificare il testo in maniera veloce ed efficace. Inoltre con l'estensione di Arduino mi ha permesso di monitorare più porte seriali simultaneamente e quindi poter riscontrare in parallelo quello che succedeva in una scheda e nell'altra. Inutile dire che ha velocizzato estremamente lo sviluppo del codice.
Per l'upload del codice su ESP8266, arrivato il momento di programmare l'interfacciamento con il cloud, ho dovuto usare la versione online dell'Arduino IDE, il quale è appositamente pensato per comunicare alla scheda in fase di upload tutte le informazioni necessarie per connettersi al cloud nonché gestire le dipendenze dalle librerie del Cloud. Previa installazione di un agent apposito per interfacciarsi alle schede.
Remo-te | 16

### Interfacciamento al Cloud

Interfacciarsi al cloud, sebbene sembrasse estremamente facile visti i tutorial, è stato brigoso poiché era la prima volta che utilizzavo una tecnologia simile.
Dopo averci speso qualche giorno tra tutorial, testing e debug, sono riuscito a
- rendere visibile la scheda al cloud
- fare l'upload codice
- orchestrare tutte le funzioni e le variabili in modo che funzionassero correttamente tra loro.

## Risultati ottenuti

I risultati ottenuti sono soddisfacenti da un punto di vista funzionale, in quanto il dispositivo riesce con successo a preparare dalle due alle quattro tazze di te, purtroppo il funzionamento non è garantito al 100% in quanto ci sono ancora alcuni aspetti da perfezionare come il sistema di caduta che non è affidabile al 100%. Ciònonostante i video del funzionamento sono reperibili al link [9] insieme alle foto dei componenti utilizzati.
La replicabilità è legata a molte variabili, ma le principali sono il tipo di bollitore e il tipo di motore. Per il resto non è un processo a cui ci si può attenere passo passo, è più una guida su come io ho risolto i vari problemi che mi si sono presentati davanti.

## Sviluppi futuri

Il dispositivo attualmente dispone delle funzionalità essenziali ma sicuramente c'è un ampio margine di miglioramento delle prestazioni.
A partire da un sistema di caduta più affidabile, in quanto quello attuale non riesce a garantire funzionamento ogni volta, sebbene la problematica non si presenti così di frequente. Tra gli altri sviluppi futuri posso pensare a:
Remo-te | 17

### Telegram bot

Sebbene l'applicazione IoT Remote di Arduino sia già abbastanza comoda, si può pensare all'implementazione di un BOT di Telegram che si occupa autonomamente di gestire la comunicazione con il cloud.

### Aggiunta parametri come zucchero e tempo di infusione

Si può aggiungere con facilità un parametro che gestisca il tempo di infusione, in quanto è una variabile che modifica la durata di una determinata porzione della preparazione. Cosa che avviene già a seguito della scelta del numero di tazze, perciò basterebbe replicare quel codice.
Per lo zucchero invece occorre progettare e mettere in funzione una appendice del dispositivo in grado di gestire la quantità di zucchero erogata.

### Aggiunta di sensori

Fotoresistore
Sebbene sia una problematica che si presenta molto poco di frequente, a volte accade che il dispositivo di accensione del bollitore fallisca ad accenderlo. Perciò si può pensare all'aggiunta di un sensore come un foto resistore capace di verificare che la luce del bollitore rimanga accesa e che quindi possa essere in grado di comunicare al dispositivo di effettuare un nuovo tentativo di accensione. Temperatura e ventola
Un'altra problematica che in teoria è gestita ma in pratica non è garantito che lo sia, è il surriscaldamento del driver del motore. Esso nonostante abbia un dissipatore integrato non è garantito che riesca a mantenere la temperatura del chip sotto la soglia limite. Si potrebbe perciò aggiungere un sensore di temperatura e una piccola ventola che possa essere accesa nel caso in cui la temperatura del chip raggiunga una determinata soglia.

## Open Source

Il progetto è libero e documentato interamente con tanto di aggiornamenti giornalieri su GitHub al link [8]

Remo-te | 18

## Bibliografia e Sitografia

Riguardo ai Motori passo passo
[1] https://youtu.be/aKxi7B4-d2U Science Fun
[2] https://www.youtube.com/watch?v=aKxi7B4-d2U
[3] https://www.youtube.com/watch?v=O2LWTBfQ26s Riguardo all’alloggio 3D per il cuscinetto a sfera
[4] https://www.thingiverse.com/hondjog1/designs
[5] https://www.thingiverse.com/thing:4111647
Riguardo ai Transistor per gestire voltaggi differenti
[6] https://electronics.stackexchange.com/questions/296330/how-to-drive-a-relay-from-esp8266-gpio (https://electronics.stackexchange.com/questions/296330/how-to-drive-a-relay-from-esp8266-gpio)
Riguardo al Design del circuito
[7] https://www.circuit-diagram.org/editor/
Riguardo alla documentazione GitHub
[8] https://github.com/LobinArcolungo/Remo-te
[9] https://github.com/LobinArcolungo/Remo-te/tree/main/photos
Remo-te | 19

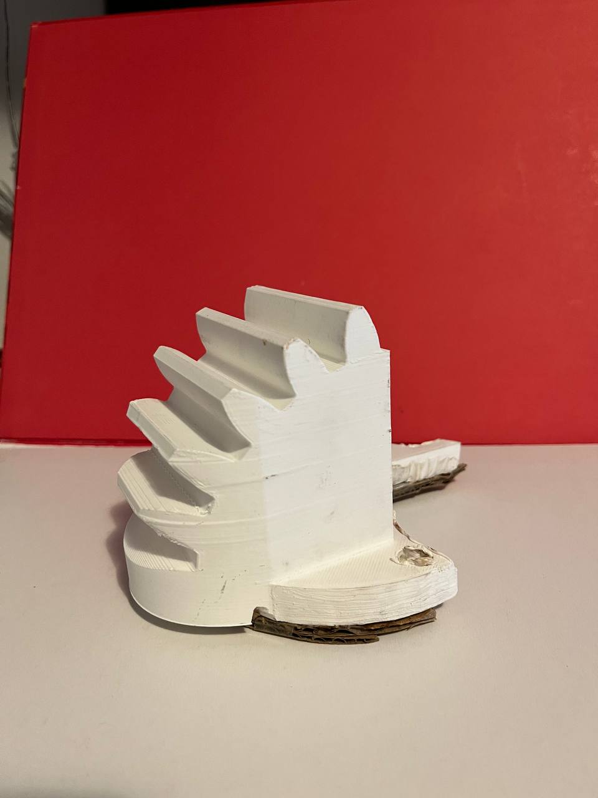
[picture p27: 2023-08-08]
photos/gear.jpg

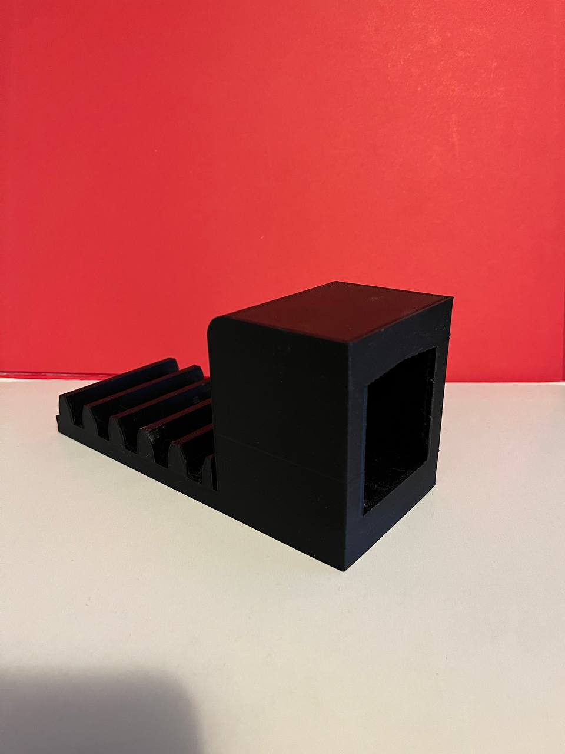
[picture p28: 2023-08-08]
photos/dock_angle.jpg

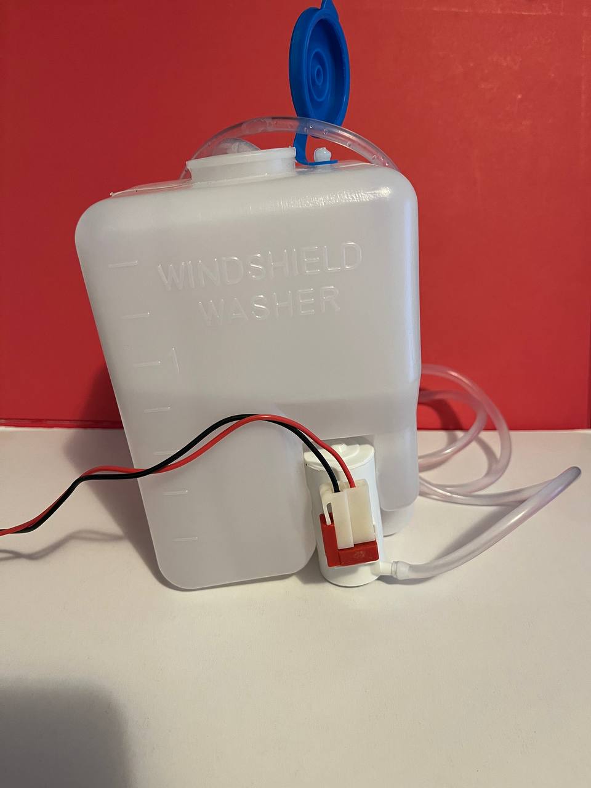
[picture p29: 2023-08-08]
photos/pump_with_tank.jpg

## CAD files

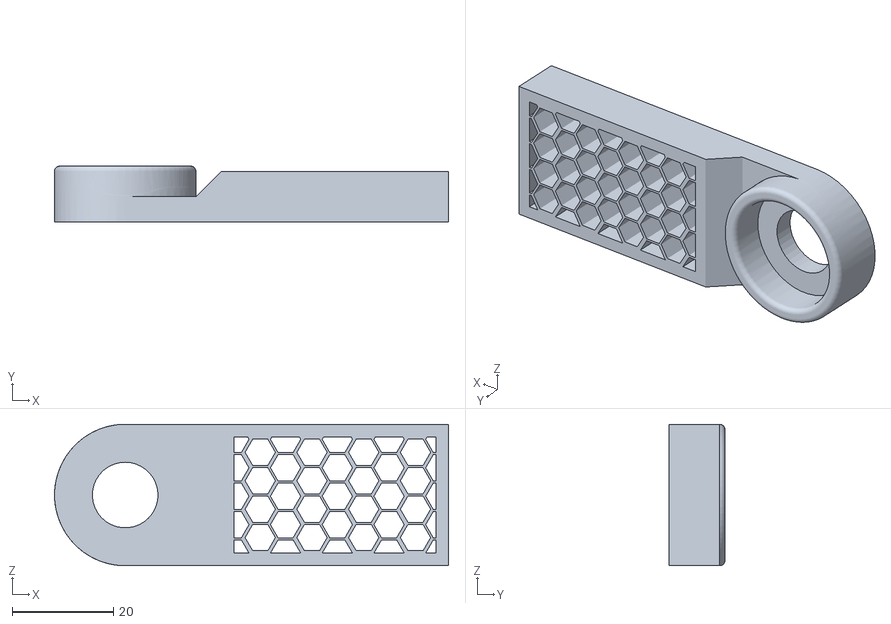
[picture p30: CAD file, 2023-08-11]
prints/bearing_housing.stl
78.0 x 11.1 x 28.0

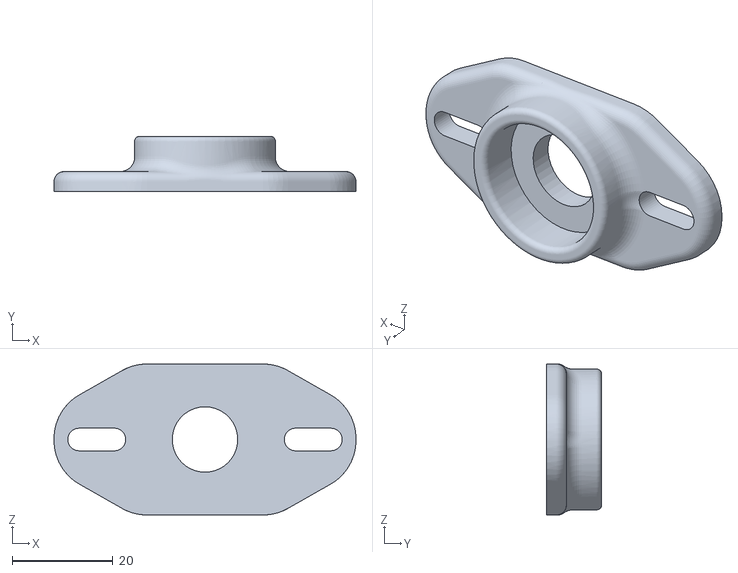
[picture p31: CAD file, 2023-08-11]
prints/lagerhuis_kogellager.STL
60.0 x 11.0 x 30.0

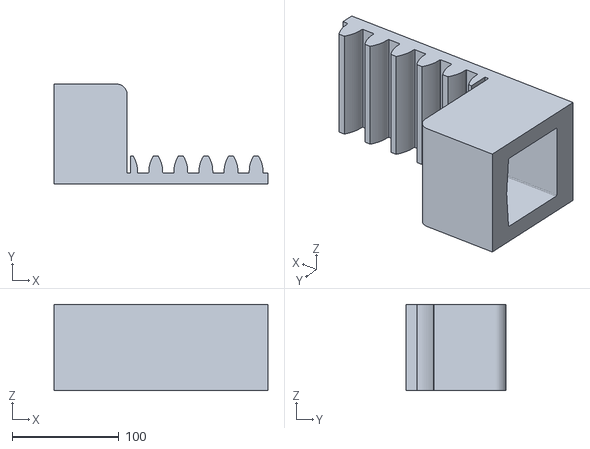
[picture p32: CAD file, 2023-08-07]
prints/remo_te_dock.stl
200.5 x 93.6 x 80.6

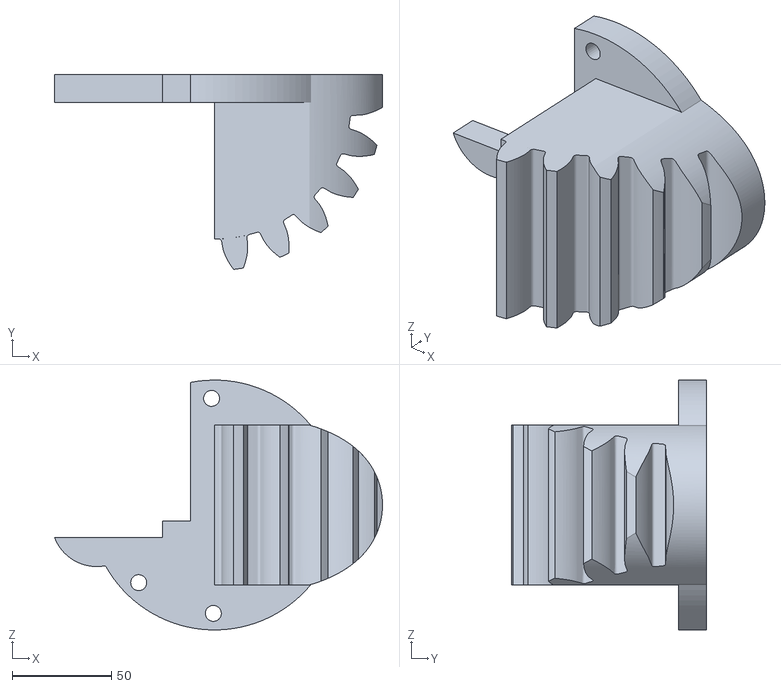
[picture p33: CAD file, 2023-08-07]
prints/remo_te_boiler.stl
165.4 x 98.2 x 126.0

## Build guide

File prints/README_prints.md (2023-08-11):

# Description of the files:

'remo_te_boiler.stl' and 'remo_te_dock.stl' are the main pieces which do most of the job of pouring without making the boiler spilling the water.

'bearing_housing.stl' is the piece who holds the bearing and helps the flowing of the rope decreasind the friction. I designed it starting from the file 'lagerhuis_kogellager.STL' from Hondjog1 downloaded from thingiverse at link: https://www.thingiverse.com/thing:4111647

Feel free to download and modify any of these pieces, expecially because you must modify the remo_te_boiler.stl accordingly to your specific type of boiler

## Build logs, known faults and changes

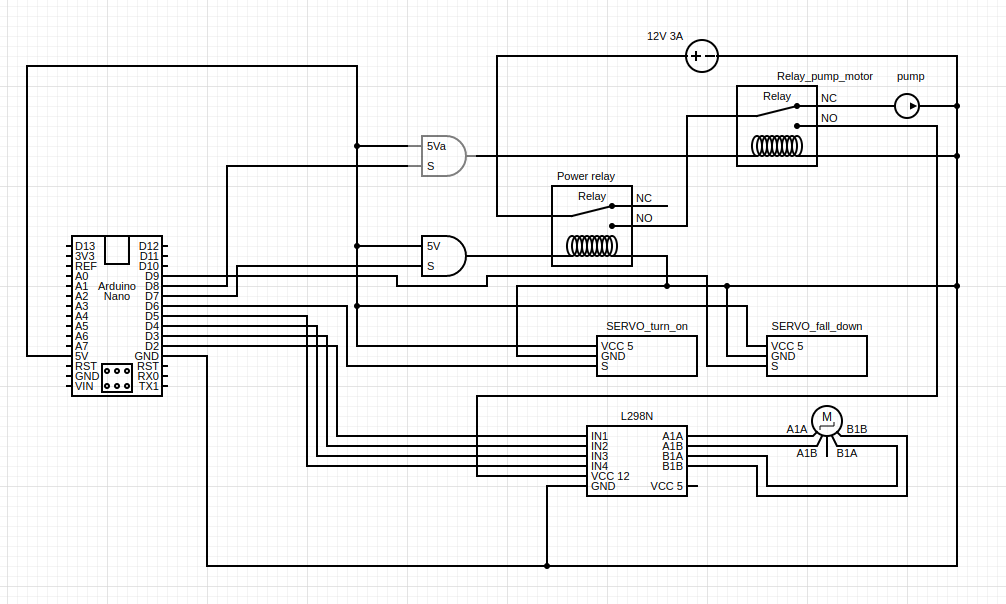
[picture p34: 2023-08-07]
circuit_history/circuit_Remo_te_v4_squares.png

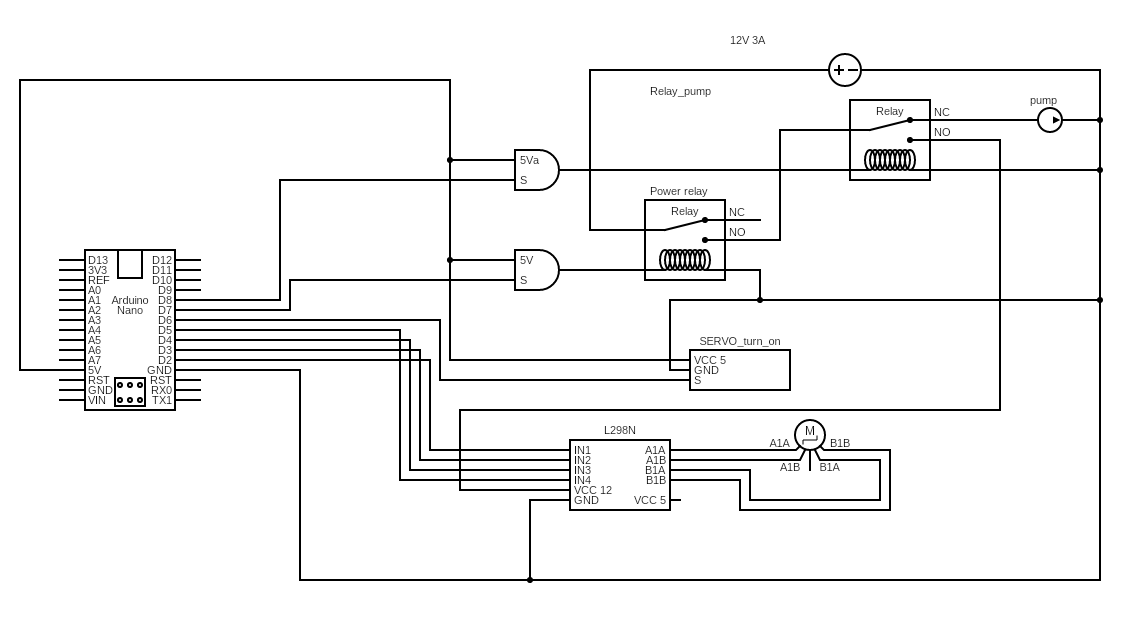
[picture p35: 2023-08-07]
circuit_history/circuit_Remo_te_v2.png

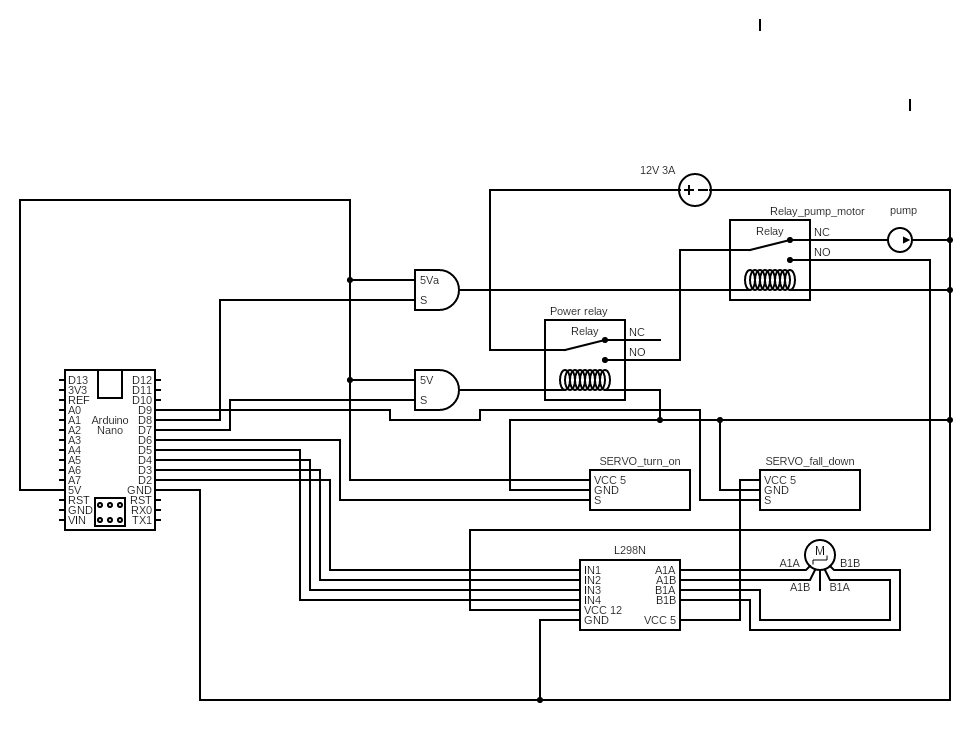
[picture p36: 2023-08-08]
circuit_history/circuit_Remo_te_v5.png

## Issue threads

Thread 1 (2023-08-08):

water suppply pipe must be inserted in some way into the boiler in order to fill it with water

LobinArcolungo, 2023-08-08:
the cap of the boiler must be closed to make the boiler turn off by himself

LobinArcolungo, 2023-08-08:
a hole has been pierced into the cap of the boiler and the water pipe slid inside. it should stand the high temperatures but we'll see

Closed 2023-08-08.

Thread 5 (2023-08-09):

!!!!!!!!!!!!!!! esp gives in output a very low amp AND VOLTAGE value so RELAYS AND SERVOMOTOR will not work

LobinArcolungo, 2023-08-09:

LobinArcolungo, 2023-08-11:
Update: servomotors can work with 3.3v vut they are not gonna have enough power to move the boiler. so i am taking an external 5V 1A power supply to provide power either to the ESP and to the servo motors AND to the relays. for those probably i will need a transistor

LobinArcolungo, 2023-08-12:
i am using two transistors for the relais but for the servo motors it's enough the 3.3 v of the ESP

LobinArcolungo, 2023-08-13:
servo motors and relays work

Closed 2023-08-13.

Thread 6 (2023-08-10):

Twine and rubber band can be substituted with nylon rope and transparent rubber band to give a more elegant look

LobinArcolungo, 2023-08-10:

LobinArcolungo, 2023-08-12:
done, but the servo which turns on the boiler MUST be fixed

Closed 2023-08-16.

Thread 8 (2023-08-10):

it is needed to design the circuit for the ESP board according to this pinout

LobinArcolungo, 2023-08-10:
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

LobinArcolungo, 2023-08-12:
the circuit is designed, it works but it is needed still some tuning

LobinArcolungo, 2023-08-13:
the maximum output of analogic pins is 3.3v that's not enough to communicate to the driver which controls the motor the powerr needed to lift te boiler. i'll try with the esp 8266 motor shield

LobinArcolungo, 2023-08-16:
the problem is solved with an arduino nano that manages all the 5V devices and a UART comunication

Closed 2023-08-16.

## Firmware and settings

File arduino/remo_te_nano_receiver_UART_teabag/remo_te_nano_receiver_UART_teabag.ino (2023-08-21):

#include<Servo.h>
#define PUMP 0
#define MOTOR 1
const bool DEBUG= true;

/*  Test Script for testing Remo_te device. it is loaded on an arduino nano or any other 5V 
    devices and it receives from serial uart protocol commands for example from an esp 8266
    or from keyboard
// All input from ESP must be in the form "command:*" where * is the char command

's' -> 12V 3A current cutoff

'e' -> 12V 3A current powerr on motor
'd' -> Stepper Motor turn right : clockwise
'a' -> Stepper Motor turn left : counterclockwise
'x' -> initialize stepnumber
'h' -> stepper go home
'b' -> step back
'n' -> step away
'g' -> pour all the water

'p' -> Pump activate
'o' -> Pump deactivate
'l' -> Pump one liter
'k' -> Pump half liter
'j' -> Pump one liter and a half

'w' -> Servo turn on boiler

'f' -> Servo start falling

't' -> Prepare 500 ml of tea

'y' -> End tea making signal received from esp. shutting down TE_READY signal

NOTES:
to pump 
0.5 liters are needed 15 seconds
1.0 liters are needed 27 seconds
1.5 liters are needed 42 seconds
we can agree that the pumps pump 2 liters per minute 
so the milliliters that need to be pumped are pumped 
in the time provided by the following formula

seconds = milliliters * 6/100

to boil
0.5 liters are needed 100 seconds and the "falling point" is not guardanteed
1.0 liters are needed 180 seconds and the "falling point" is not guaranteed
1.5 liters are needed 240 seconds and the "falling point" is not guardanteed

so 10 seconds before automatic turning off we 

*/

// Stepper motor
const int A1A = 2;
const int A1B = 3;
const int B1A = 4;
const int B1B = 5;

int stepnumber = 0;
double mf = 2*PI/256; // microstep factor

int Pa,Pb;

const int default_movement = 2048;
const int motor_power = 150;

// Stepper Motor relative position
int steps_from_home;
const int min_steps = 0;
const int max_steps = 9;


// Power supply Relay
const int POWER_ON = 7;

// Pump_Motor selection Relay
const int PUM0_MOT1 = 8;

// Servo motor
const int SERVO = 6;
Servo boiler_turner;
int boiler_pos;

const int SERVO_FALLER = 9;
Servo boiler_faller;
int faller_pos;

// Serial Input Parsing
const int BUF_SIZE=11;
// char buf[11]; declared in loop
int rlen;

String alphabet = "qwertyuiopasdfghjklzxcvbnm";
int index_in_alphabet;
char command;

// te_ready notification pin
int te_ready;
const int TE_READY=10;

// Time management
unsigned long pump_seconds;
unsigned long boiling_timer;
unsigned long actualTime;
bool boiling;

const unsigned long INFUSION_TIME = 3UL*60UL*1000UL;
bool infusing;
unsigned long start_infusion_time;

void move(int stepnumber, int MAXpower, int wait){//maxpower is 255 usually
  Pa = (sin(stepnumber*mf)*MAXpower);
  Pb = (cos(stepnumber*mf)*MAXpower);

  if (Pa>0){
    analogWrite(A1A,Pa);
    analogWrite(A1B,0);
  }
  else{
    analogWrite(A1A,0);
    analogWrite(A1B,abs(Pa));
  }
                                                                                                                                       
  if (Pb>0){
    analogWrite(B1A,Pb);
    analogWrite(B1B,0);
  }
  else{
    analogWrite(B1A,0);
    analogWrite(B1B,abs(Pb));
  }
        powerOnMotor();

}

// !!! always call powerOff after calling any powerOn
void powerOnMotor(){
    digitalWrite(PUM0_MOT1,HIGH); //select motor
    digitalWrite(POWER_ON,HIGH);
}
void powerOnPump(){
    digitalWrite(PUM0_MOT1,LOW); //select pump
    digitalWrite(POWER_ON,HIGH);
}
void powerOff(){
    digitalWrite(POWER_ON,LOW);
}

// Motor movement !! each function leaves the power on!
void step_away(){
    if (steps_from_home<max_steps){
        powerOnMotor();
        for (int i = 0; i<default_movement;i++){
            stepnumber++;
            move(stepnumber,motor_power,1000);
        }
        steps_from_home += 1;
    }
}
void step_back(){
    if (steps_from_home>min_steps){
        powerOnMotor();
        for (int i = default_movement; i>0;i--){
            stepnumber--;
            move(stepnumber,200,1000);
        }
        steps_from_home -= 1;
    }
}
void stepper_go_home(){
    while(steps_from_home>0){
        step_back();
    }
}

void turn_on_boiler()
{
    int position;
    for(position=90;position>=0;position-=1){
        boiler_turner.write(position);
        delay(30);
        }
    for(position=0;position<=90;position+=1){
        boiler_turner.write(position);
        Serial.print(".");
        delay(30);
        }
    boiler_pos = position; //to keep track of the position outside the function
}

void fall()
{
    int position;
    powerOnMotor();
    for(position=0;position<=90;position+=1){
        boiler_faller.write(position);
        delay(30);
        }
    position = 0;
    boiler_faller.write(position);
    faller_pos = position; //to keep track of the position outside the function
}

void pumpMilliliters(int mill){
    pump_seconds = (int)(mill * 3.0/100);
    Serial.println(pump_seconds);
    if (pump_seconds >0 && pump_seconds<50){ //security limit
        powerOnPump();
        delay(pump_seconds*1000); 
        powerOff();
    }
}

unsigned long getFallingPointSeconds(int milliliters){
    
    unsigned long time =-1 ;
    if(milliliters>250){
        if (milliliters<=500){
            time = 100UL;
        }
        else if (milliliters<=1000){
            time = 180UL;
        }
        else if (milliliters<=1500){
            time = 240UL;
        }
        else{
            time = 250UL;
        }
    }
    return time;
}

void setup() {
    //Stepper motor
    pinMode(A1A,OUTPUT);
    pinMode(A1B,OUTPUT);
    pinMode(B1A,OUTPUT);
    pinMode(B1B,OUTPUT);

    // Power supply Relay
    pinMode(POWER_ON,OUTPUT);

    // Pump_Motor selection Relay
    pinMode(PUM0_MOT1,OUTPUT);

    // Servo motor
    boiler_turner.attach(SERVO);
    boiler_pos=90;
    boiler_turner.write(boiler_pos);

    boiler_faller.attach(SERVO_FALLER);
    faller_pos=0;
    boiler_faller.write(faller_pos);

    // Stepper motor position
    steps_from_home=0;

    //time management
    boiling = false;
    actualTime = 0;

    infusing = false;
    start_infusion_time = 0;

    //TE_READY notification pin
    pinMode(TE_READY,OUTPUT);
    te_ready=LOW;
    digitalWrite(TE_READY,te_ready);

    Serial.begin(74880);
    if (DEBUG) Serial.print("Arduino nano setup ended! ");
    
}

void loop() {
    if (Serial.available()){
        char buf[11];
        // Start of input parsing verification. this should get rid of the garbage input coming from the esp
        // All input from ESP must be in the form "command:*" where * is the char command
        rlen = Serial.readBytes(buf,BUF_SIZE);
        String comm = buf;

        if(rlen == 9){
            String sub = comm.substring(0,8);
            if (sub.equals("command:"))
                command = buf[rlen-1];
                index_in_alphabet = alphabet.indexOf(command);
        }
        else{
            index_in_alphabet = -1;
        }
        // End of input parsing verification
        
        if (index_in_alphabet>=0){
            Serial.print("Received form Serial: '");
            Serial.print(command);
            Serial.println("'");
        }

        if(rlen == 11){
            String te = comm.substring(8,10);
            String sub = comm.substring(0,8);
            if (sub.equals("command:") && te.equals("TE")){
                char c_cups [1];
                c_cups[0]= buf[rlen-1];
                int n_cups = atoi(c_cups);
                if (DEBUG) Serial.print("Arduino nano is going to prepare ");
                if (DEBUG) Serial.print(n_cups);
                if (DEBUG) Serial.println(" cups of tea");
                prepareTea(n_cups*250);

            }
            else{
                if (DEBUG) Serial.print("11:");
                if (DEBUG) Serial.println(comm);
            }
        }

        
        memset(buf,0, sizeof(buf));
        Serial.flush();
        rlen=0;

    }
    else command= 'i'; //idle: no commands

    // Current Cutoff
    if (command == 's') {//PowerOff
        powerOff();
    }

    //Stepper Motor

    if (command == 'd') { //Right: clockwise
        powerOnMotor();
        for (int i = 0; i<default_movement;i++){
            stepnumber++;
            move(stepnumber,motor_power,1000);
        }
    }
    if (command == 'a') {//Left: clockwise
        powerOnMotor();
        for (int i = default_movement; i>0;i--){
            stepnumber--;
            move(stepnumber,200,1000);
        }
    }
    if (command == 'e') {//power on
        powerOnMotor();
    }
    if (command == 'x') {
        stepnumber=0;
        powerOnMotor();
        move(stepnumber,motor_power,1000);
        powerOff();
    }
    if (command == 'h') {
        stepper_go_home();
    }
    if (command == 'b') {
        step_back();
    }
    if (command == 'n') {
        step_away();
    }
    if (command == 'g') {//pour all the water
        pourAllTheWater();
    }

    //Pump

    if (command == 'p') {//PowerOn
        powerOnPump();
    }
    if (command == 'o') {//PowerOff
        powerOff();
    }
    if (command == 'l') {//Fill one liter
        pumpMilliliters(1000);
    }
    if (command == 'k') {//Fill half liter
        pumpMilliliters(500);
    }
    if (command == 'j') {//Fill one liter and a half
        pumpMilliliters(1500);
    }

    //Servo 

    if (command == 'w') {//PowerOn
        turn_on_boiler();
    }

    if (command == 'f') {//Start falling
        fall();
    }

    //Prepare TEA

    if (command == 't') {//prepare 500ml
        prepareTea(1000);
    }

    //End tea making
    if (command == 'y') {

        if (DEBUG) Serial.println("'y' signal received, now checking if te_ready is high'");
        if(te_ready == HIGH){
            if (DEBUG) Serial.println("it is.");
            te_ready = LOW;
            digitalWrite(TE_READY,te_ready);
            if (DEBUG) Serial.print("now it is: ");
            if (DEBUG) Serial.println(te_ready);

        }else{
            if (DEBUG) Serial.println("it isn't.");
        }
    }


    //check if boiling time is up
    if(boiling && millis()-actualTime>=boiling_timer){
        boiling = false;
        pourAllTheWater();           
    }
    //check if infusion time is up
    if(infusing && millis()-start_infusion_time>=INFUSION_TIME){
        infusing = false;

        if (DEBUG) Serial.println("Infusion terminated!");
        endTeaPreparation();           
    }
}

void prepareTea(int milliliters){
    boiling_timer = getFallingPointSeconds(milliliters);

    if(milliliters>250 && milliliters<=1500 && boiling_timer>0){ //security parameters

        if (DEBUG) Serial.println("Start pumping");

        pumpMilliliters(milliliters);
        
        if (DEBUG) Serial.println("Finished pumping, turning on boiler");

        turn_on_boiler();
        
        //now wait until ten seconds from the turning off point

        if (milliliters>1000 && milliliters<=1500)
            boiling_timer -=10;

        if (DEBUG) {Serial.print("Boiler on, now we wait ");
                    Serial.print(boiling_timer);
                    Serial.print(" seconds. ");
                    Serial.print(boiling_timer *1000UL);
                    Serial.println(" milliseconds");}

        boiling_timer = boiling_timer *1000UL;
        actualTime = millis();
        boiling =true;
    }
        
}

void pourAllTheWater(){

    if (DEBUG) Serial.println("Now stepper goes home and takes one step away");

    //now check that the stepper motor is at home position

    if (steps_from_home != 0)
        stepper_go_home();
    
    step_away(); //give enough rope to fall

    if (DEBUG) Serial.println("Now boiler falls");

    fall();

    if (DEBUG) Serial.println("Boiler fell, now wait ten seconds and start pouring");

    delay(10*1000);
    //now the boiler should be turned off
    
    //pour hot water in three steps
    step_away();
    step_away();
    step_away();
    step_away();
    if (DEBUG) Serial.println("Positioning done, now pouring and wait 8 seconds each pouring");
    step_away();
    delay(8000);
    step_away();
    delay(8000);
    step_away();
    delay(8000);
    step_away();
    delay(8000);
    step_away();
    delay(8000);

    powerOff(); //always power off motor

    //now start infusing process

    if (DEBUG) Serial.println("Now start infusing process");

    start_infusion_time = millis();
    infusing =true;
}
void endTeaPreparation(){

    if (DEBUG) Serial.println("Now stepper go home");
    //reel the rope 
    stepper_go_home();

    //reel the last bit
    steps_from_home+=1;
    stepper_go_home();

    if (DEBUG) Serial.println("finally shut power off");

    powerOff();

    //send TE_READY signal to ESP
    Serial.println("TE_READY");
    te_ready=HIGH;
    digitalWrite(TE_READY,te_ready);

    return;
    
}

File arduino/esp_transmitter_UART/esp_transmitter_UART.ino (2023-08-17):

// Serial Input Parsing
const int BUF_SIZE=10;
char buf[10];
int rlen;

String alphabet = "qwertyuiopasdfghjklzxcvbnm";
int index_in_alphabet;

void setup() {  
  pinMode(D2,OUTPUT);
  Serial.begin(74880);               // initialize serial communication at 74880 bits per second:
  Serial1.begin(74880);            // initialize UART with baud rate of 74880

}
void loop() {
  if (Serial.available()){
    rlen = Serial.readBytes(buf,BUF_SIZE);
    Serial.print("Received form Serial: ");
    Serial.println(buf);
    index_in_alphabet = alphabet.indexOf(buf[0]);
    if (index_in_alphabet>=0){
        String message = "command:";
        message.concat(buf[0]);
        Serial.println(index_in_alphabet);
        Serial.print("sending:");
        Serial.println(message);
        Serial1.print(message);
    }
  }
}

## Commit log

2023-08-08 Today I completely disassembled the first prototype made from a cardboard box and reassembled everything inside an IKEA plastic box. plastic box from IKEA.
    Afterwards, during reassembly, I worked on perfecting the drop system driven by the second servo motor.
    After various trials and errors, I arrived at a functioning version of the mechanism, also thanks to the change of the servo power supply. Previously, the servo took power from the arduino and did not have enough power, whereas now it is connected to the stepper motor management chip and therefore also has to be powered by the relais
    solved the problem of the motor making strange sounds by setting the default step number to a power of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
2023-08-11 changes and news from 10 august
    [bearing_housing.stl, lagerhuis_kogellager.STL, remo_te_boiler.stl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]
2023-08-13 new circuits and journals
2023-08-17 commit with a lot of updates, a video of a functioning demonstration, working code, new circuitry and a new readme file!. The fritzing image is yet to be made
2023-08-18 update circuit
